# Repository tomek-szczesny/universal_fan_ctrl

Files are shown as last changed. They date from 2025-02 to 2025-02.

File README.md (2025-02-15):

# universal_fan_ctrl

An autonomous, temperature dependent fan controller

The aim of the project is to develop a fan controller module that can be applied to fans in existing appliances that otherwise have no speed control. The module is intended to be connected as a pass-through between the fan and its original power source.

2025-02-15-212940_507x466_scrot
2025-02-15-212955_443x396_scrot

## Features

- 4.5V - 30V input voltage range
- Low side 1A PWM switch controls any DC fan, with of without PWM pin
- 11.6 x 13.6 mm 2-layer PCB, no bottom side components
- Cheap BOM with hand-solderable 0603 passives
- BOM-configurable parameters
- 2.54mm pitch input and output THT pads for wires or connectors
- On-board or remote temperature sensor (DS18B20), or AVR internal sensor

## Operation

- PWM fixed at 100Hz
- In absence of DS18B20 temperature sensor, falls back to the internal AVR sensor
- Temperature probed at 5Hz
- Digital low pass filters reduce measurement noise
- Configurable Maximum temperature (MT) and Temperature ramp length (TR)
  -   Fan stays off at T < (MT-TR)
  -   Fan's PWM is mapped to (23.2% - 100%) range within (MT-TR) < T < MT range
  -   Fan stays fully on at T > MT

## Configuration

The microcontroller senses two ADC values on startup, which determine mode of operation. They can be easily changed by replacing two resistors on board.

### Maximum temperature (MT)

The temperature at which the fan works at the maximum speed. Resistor Rmt controls this parameter.

| Max Temperature | Rmt value  |
| --- | --- |
| 30C | Open |
| 35C | 68k |
| 40C | 33k |
| 45C | 20k |
| 50C | 12k |
| 55C | 6k8 |
| 60C | 3k6 |
| 65C | 1k or less |

### Ramp length (TR)

The temperature range that is mapped linearly to 23.2% - 100% PWM output This parameter is controlled by resistor Rtr.

| Ramp Length | Rtr value |
| --- | --- |
| 2.5C | Open |
| 5C | 33k |
| 10C | 12k |
| 20C | 2k7 or less |

## Schematic
2025-02-15-213155_895x945_scrot

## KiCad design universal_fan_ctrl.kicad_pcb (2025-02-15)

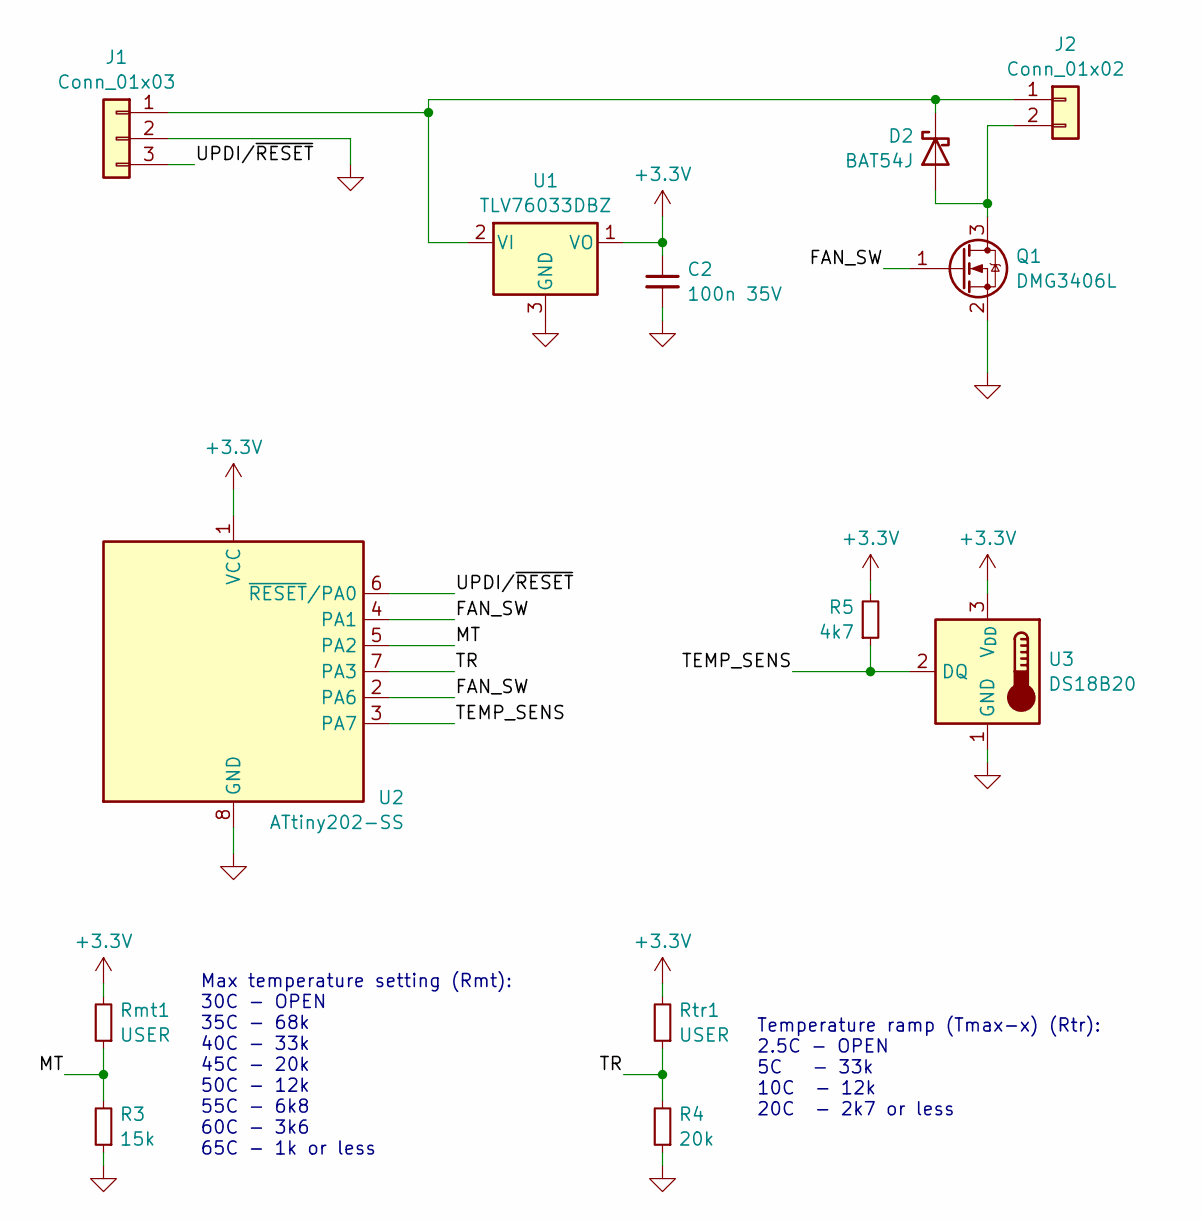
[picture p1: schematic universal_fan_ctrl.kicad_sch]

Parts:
C2: 100n 35V; R_0603_1608Metric; LCSC C14663
D2: BAT54J; D_SOD-323F
J1: Conn_01x03; PinHeader_1x03_P2.54mm_Vertical
J2: Conn_01x02; PinHeader_1x02_P2.54mm_Vertical
Q1: DMG3406L; SOT-23; LCSC C460978
R3: 15k; R_0603_1608Metric; LCSC C22809
R4: 20k; R_0603_1608Metric; LCSC C4184
R5: 4k7; R_0603_1608Metric; LCSC C23162
Rmt1: USER; R_0603_1608Metric; LCSC C4184
Rtr1: USER; R_0603_1608Metric; LCSC C22790
U1: TLV76033DBZ; SOT-23; LCSC C2683368
U2: ATtiny202-SS; SOIC-8_3.9x4.9mm_P1.27mm; LCSC C2052951
U3: DS18B20; TO-92_Inline

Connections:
+3.3V: C2.1, R5.2, Rmt1.2, Rtr1.2, U1.1 (VO), U2.1 (VCC), U3.3 (V_{DD})
/FAN_SW: Q1.1 (G), U2.2 (PA6), U2.4 (PA1)
/MT: R3.2, Rmt1.1, U2.5 (PA2)
/TEMP_SENS: R5.1, U2.3 (PA7), U3.2 (DQ)
/TR: R4.2, Rtr1.1, U2.7 (PA3)
/UPDI/~RESET: J1.3, U2.6 (~RESET/PA0)
GND: C2.2, J1.2, Q1.2 (S), R3.1, R4.1, U1.3 (GND), U2.8 (GND), U3.1 (GND)
unnamed: D2.2 (A), J2.2, Q1.3 (D)
unnamed: D2.1 (K), J1.1, J2.1, U1.2 (VI)

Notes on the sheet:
Temperature ramp (Tmax-x) (Rtr): 2.5C - OPEN 5C - 33k 10C - 12k 20C - 2k7 or less
Max temperature setting (Rmt): 30C - OPEN 35C - 68k 40C - 33k 45C - 20k 50C - 12k 55C - 6k8 60C - 3k6 65C - 1k or less

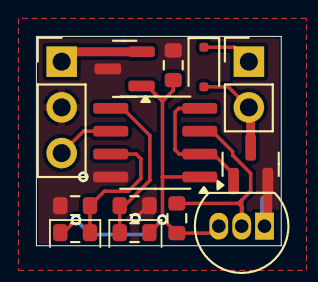
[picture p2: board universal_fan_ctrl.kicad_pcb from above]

Board: 2 copper layers, 13.6 x 11.6 mm, 13 parts (0 on the bottom side), 9 nets.

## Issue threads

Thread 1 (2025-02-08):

HW fixes

tomek-szczesny, 2025-02-08:
- Add a freewheeling diode (if possible)
MOSFET with exceeded VDS rating probably will act as a Zener diode, but let's not test this.
- Mark USER resistors more clearly
- Update schematics in the README

Closed 2025-02-15.

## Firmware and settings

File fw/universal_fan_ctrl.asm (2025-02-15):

; Universal Fan Controller
; Attiny202 firmware
; by Tomek Szczęsny 2025
; Build with avra

; Fuse bits:
; - Set osc to 16MHz

.nolist
.include "tn202def.inc"
.list

; temperatures are stored as 16-bit signed integers
; representing temperature in units of (1/16) deg C
; [t11 t10 t9 t8 t7 t6 t5 t4] : [t3 t2 t1 t0 t-1 t-2 t-3 t-4]

.equ owp = 7				; One-Wire pin number on port A

.def arg1 = r25				; procedure io
.def arg0 = r24
.def tempminh = r23			; 25% PWM temperature
.def tempminl = r22
.def tmph = r21				; Temporary values
.def tmpl = r20
.def slope = r19			; The slope constant for PWM calculation
.def temph = r17			; Current temperature
.def templ = r16
.def tempmaxh = r9			; 100% PWM temperature
.def tempmaxl = r8
.def zero = r7				; Always zero

.macro wait12u
	push arg0		; 1 cycle
	ldi arg0, 1		; 1 cycle
	rcall delay		; 8 cycles in total
	pop arg0		; 2 cycles
.endm
.macro wait15u
	push arg0		; 1 cycle
	ldi arg0, 2		; 1 cycle
	rcall delay		; 11 cycles in total
	pop arg0		; 2 cycles
.endm
.macro wait60u
	push arg0		; 1 cycle
	ldi arg0, 17		; 1 cycle
	rcall delay		; 56 cycles in total
	pop arg0		; 2 cycles
.endm
.macro wait67u
	push arg0		; 1 cycle
	ldi arg0, 19		; 1 cycle
	rcall delay		; 62 cycles in total
	pop arg0		; 2 cycles
	nop			; 1 cycle
.endm
.macro wait480u
	push arg0		; 1 cycle
	ldi arg0, 157		; 1 cycle
	rcall delay		; 476 cycles in total
	pop arg0		; 2 cycles
.endm

; One Wire macros, may destroy r30 data

.macro owh				; One wire goes high
	sbi VPORTA_OUT, owp
.endm
.macro owl				; One wire goes low
	cbi VPORTA_OUT, owp
.endm
.macro owz				; One wire goes hi-Z (input)
	cbi VPORTA_DIR, owp
.endm
.macro owe				; One wire output enabled
	sbi VPORTA_DIR, owp
.endm
.macro owr				; One wire read input to flag T
	in r30, VPORTA_IN
	bst r30, owp
.endm

; ------------------------------------------------------------ 

.cseg
.org 000000				; Interrupt Vector
	rjmp Init			; Reset

.org TCB0_INT_vect			; The main loop at 5Hz
	rjmp Loop

.org INT_VECTORS_SIZE+1
Init:
	ldi tmpl, Low(RAMEND)		
	out CPU_SPL, tmpl		; Stack pointer init

	clr zero			; Populate "always zero" register

	ldi tmpl, CPU_CCP_IOREG_gc	; Unlocking Configuration Change Protection
	out CPU_CCP, tmpl
	ldi tmpl, 0b00000111		; Clock prescaler dividing by 16 -> 1MHz operation
	sts CLKCTRL_MCLKCTRLB, tmpl
	ldi tmpl, 0b00000001		; Enabling sleep mode "Idle"
	sts SLPCTRL_CTRLA, tmpl

; ------------------------------------------------------------ 

	; Sampling BOM settings set by resistor dividers

	ldi tmpl, 0x05			; Enable ADC, 10 bit
	sts ADC0_CTRLA, tmpl
	ldi tmpl, 0x02			; Accumulation of 4 results
	sts ADC0_CTRLB, tmpl
	ldi tmpl, 0b01010000		; Reduced sampling cap, Vref=Vdd, clk divided by 2
	sts ADC0_CTRLC, tmpl
	ldi tmpl, 0b01000000		; 32 clock cycles init delay
	sts ADC0_CTRLD, tmpl
	ldi tmpl, 31			; Sampling period of 32 clk cycles (maximum)
	sts ADC0_SAMPCTRL, tmpl
	ldi tmpl, 0x02			; Selects PA2 input (MT value)
	sts ADC0_MUXPOS, tmpl
	rcall ADCpoll			; Capture the value

	lds tmph, ADC0_RESH		; Load the ADC result, raw setting on lower nibble
	ldi tmpl, 80			; *16*5, shift and scale setting
	mul tmph, tmpl
	movw tempmaxl, r0
	ldi tmpl, 0xE0			; Offset the value by +30C (30*16)
	ldi tmph, 0x01
	add tempmaxl, tmpl
	adc tempmaxh, tmph

	ldi tmpl, 0x00			; Disable Accumulation
	sts ADC0_CTRLB, tmpl
	ldi tmpl, 0x03			; Selects PA3 input (TR value)
	sts ADC0_MUXPOS, tmpl
	rcall ADCpoll			; Capture the value

	lds tmph, ADC0_RESH		; Load the ADC result, raw setting on low 2 bits
	inc tmph			; Calculate the low threshold (tempmin)
	clr tempminh
	ldi tempminl, 0x14		; 1.25C constant, to be multiplied by 2 (TR+1) times
	ldi slope, 0x60			; 6*16 const, to be divided by 2 (TR+1) times
	tempminloop:			; (TR+1) loop
	lsl tempminl
	rol tempminh
	lsr slope
	dec tmph
	brne tempminloop
	movw tmpl, tempmaxl		; Calculate tempmin = tempmax - dT
	sub tmpl, tempminl
	sbc tmph, tempminh
	movw tempminl, tmpl		; move the result to tempmin

	sts ADC0_CTRLA, zero		; Disable ADC

; ------------------------------------------------------------ 

	; Set up the counters
	; TCA will generate the PWM signal at WO1 pin, at 100Hz or so
	; TCB will generate 5Hz interrupts for temperature acquisition

	; TCA setup
	ldi tmpl, 0x05			; TCA enabled, divider by 4 (=250kHz) 
	sts TCA0_SINGLE_CTRLA, tmpl
	ldi tmpl, 0b00100011		; WO1 enabled, Single Slope PWM mode 
	sts TCA0_SINGLE_CTRLB, tmpl
	ldi tmpl, 0x02			; Set PA1 as output
	sts PORTA_DIRSET, tmpl
	ldi tmpl, 0xC3			; Set the period to 100Hz (2499) 
	sts TCA0_SINGLE_TEMP, tmpl
	ldi tmpl, 0x09
	sts TCA0_SINGLE_PERH, tmpl

	; TCB Setup
	ldi tmpl, 0x07
	sts TCB0_CTRLA, tmpl		; TCB enabled, 250kHz ckock from TCA_CLK
	sts TCB0_CTRLB, zero		; Periodic interrupt mode
	ldi tmpl, 0xC3			; Set 5Hz period (49999)
	sts TCB0_CCMPH, tmpl
	ldi tmpl, 0x4F
	sts TCB0_CCMPL, tmpl
	ldi tmpl, 0x01			; Enable Interrupt on Capture
	sts TCB0_INTCTRL, tmpl

; ------------------------------------------------------------ 

	; Configuration of ADC for capturing AVR internal temperature

	ldi tmpl, 0x10			; Vref = 1.1V
	sts VREF_CTRLA, tmpl
	ldi tmpl, 0x01			; Enable ADC
	sts ADC0_CTRLA, tmpl
	ldi tmpl, 0x06			; Accumulation of 64 results
	sts ADC0_CTRLB, tmpl
	ldi tmpl, 0b01000000		; Reduced sampling cap, internal Vref, clk divided by 2
	sts ADC0_CTRLC, tmpl
	ldi tmpl, 0b00100000		; 16 clock cycles init delay (min 16 at this clk rate)
	sts ADC0_CTRLD, tmpl
	ldi tmpl, 14			; Sampling period of 2+14 clk cycles
	sts ADC0_SAMPCTRL, tmpl
	ldi tmpl, 0x1E			; Selects temperature sensor as the ADC input
	sts ADC0_MUXPOS, tmpl

	rcall AVRtemp			; Set up the temp registers with an initial value
	movw templ, tmpl
	rcall PWMset

; ------------------------------------------------------------------------------

	sei				; Enable interrupts
				
	; Fall through to the Oblivion, awaiting interrupts

; ------------------------------------------------------------------------------ 

Oblivion:
	sleep
	rjmp Oblivion

; ------------------------------------------------------------------------------
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

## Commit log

2025-02-01 Initial commit - Hardware ready
    [universal_fan_ctrl-CuBottom.gbr, universal_fan_ctrl-CuTop.gbr, universal_fan_ctrl-EdgeCuts.gbr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]
2025-02-02 Schematic clean-up
    [universal_fan_ctrl.kicad_sch]
2025-02-05 Connected FAN_CTRL net to the spare AVR pin
    [universal_fan_ctrl-CuBottom.gbr, universal_fan_ctrl-CuTop.gbr, universal_fan_ctrl-EdgeCuts.gbr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]
2025-02-14 PWM section complete
2025-02-15 kicad update, addressing #1
    [universal_fan_ctrl-CuBottom.gbr, universal_fan_ctrl-CuTop.gbr, universal_fan_ctrl-EdgeCuts.gbr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]
